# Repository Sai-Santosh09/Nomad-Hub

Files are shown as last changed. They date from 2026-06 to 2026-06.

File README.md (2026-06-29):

# NomadHub

NomadHub is a compact travel-inspired USB hub PCB designed in **KiCad**. It provides reliable USB connectivity through one USB Type-C upstream port, two USB Type-C downstream ports, and two USB Type-A downstream ports using the SL2.1S USB 2.0 Hub Controller.

## Features

- Compact travel-friendly PCB
- USB Type-C upstream port
- 2 × USB Type-C downstream ports
- 2 × USB Type-A downstream ports
- SL2.1S USB 2.0 Hub Controller
- 2-layer PCB design
- USB 2.0 compliant routing
- Gerber files included

## Images




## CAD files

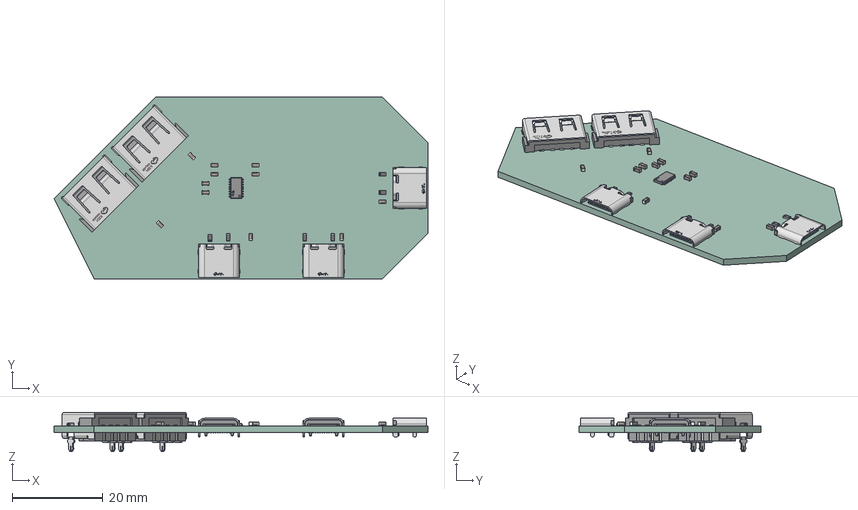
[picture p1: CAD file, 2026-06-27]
.step
82.3 x 40.0 x 8.60 mm
C_0603_1608Metric x 11
R_0603_1608Metric x 6
USB-C-SMD_TYPE-C-6PIN-2MD-073 x 3
SSOP-16_L4.6-W2.6-P0.53-LS4.0-BL
USB-A-TH_10.0QHHTZB6.3 x 2
USB Hub_PCB

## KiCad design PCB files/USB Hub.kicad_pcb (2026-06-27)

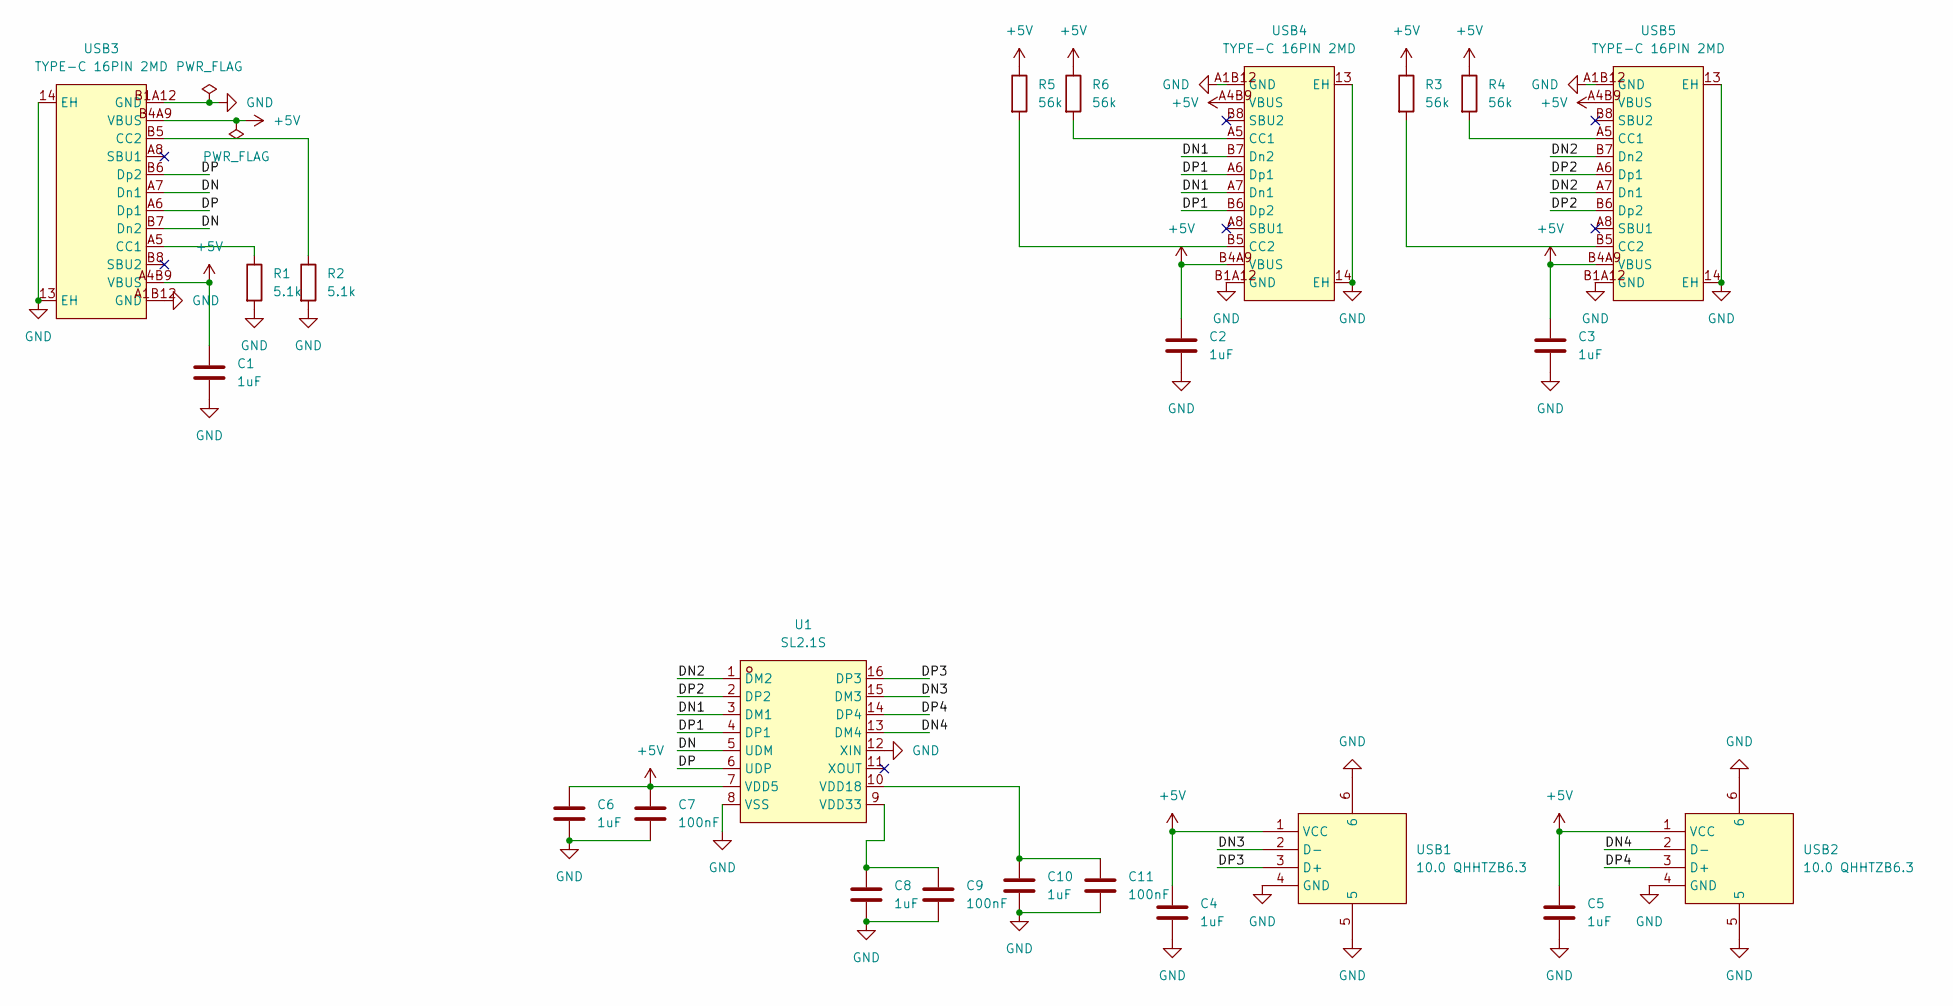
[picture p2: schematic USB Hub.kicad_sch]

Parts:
C1, C2, C3, C4, C5, C6, C8, C10: 1uF; C_0603_1608Metric
C7, C9, C11: 100nF; C_0603_1608Metric
R1, R2: 5.1k; R_0603_1608Metric
R3, R4, R5, R6: 56k; R_0603_1608Metric
U1: SL2.1S; SSOP-16_L4.6-W2.6-P0.53-LS4.0-BL; MPN SL2.1s; LCSC Part C2684433
USB1, USB2: 10.0 QHHTZB6.3; USB-A-TH_10.0QHHTZB6.3; MPN 10.0 QHHTZB6.3; LCSC Part C668591
USB3, USB4, USB5: TYPE-C 16PIN 2MD; USB-C-SMD_TYPE-C-16PIN-2MD-073; MPN TYPE-C 16PIN 2MD(073); LCSC Part C2765186

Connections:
+5V: C1.1, C2.1, C3.1, C4.1, C5.1, C6.1, C7.1, R3.1, R4.1, R5.1, R6.1, U1.7 (VDD5), USB1.1 (VCC), USB2.1 (VCC), USB3.A4B9 (VBUS), USB3.B4A9 (VBUS), USB4.A4B9 (VBUS), USB4.B4A9 (VBUS), USB5.A4B9 (VBUS), USB5.B4A9 (VBUS)
/DN: U1.5 (UDM), USB3.A7 (Dn1), USB3.B7 (Dn2)
/DN1: U1.3 (DM1), USB4.A7 (Dn1), USB4.B7 (Dn2)
/DN2: U1.1 (DM2), USB5.A7 (Dn1), USB5.B7 (Dn2)
/DN3: U1.15 (DM3), USB1.2 (D-)
/DN4: U1.13 (DM4), USB2.2 (D-)
/DP: U1.6 (UDP), USB3.A6 (Dp1), USB3.B6 (Dp2)
/DP1: U1.4 (DP1), USB4.A6 (Dp1), USB4.B6 (Dp2)
/DP2: U1.2 (DP2), USB5.A6 (Dp1), USB5.B6 (Dp2)
/DP3: U1.16 (DP3), USB1.3 (D+)
/DP4: U1.14 (DP4), USB2.3 (D+)
GND: C1.2, C2.2, C3.2, C4.2, C5.2, C6.2, C7.2, C8.2, C9.2, C10.2, C11.2, R1.2, R2.2, U1.8 (VSS), U1.12 (XIN), USB1.4 (GND), USB1.5, USB1.6, USB2.4 (GND), USB2.5, USB2.6, USB3.13 (EH), USB3.14 (EH), USB3.A1B12 (GND), USB3.B1A12 (GND), USB4.13 (EH), USB4.14 (EH), USB4.A1B12 (GND), USB4.B1A12 (GND), USB5.13 (EH), USB5.14 (EH), USB5.A1B12 (GND), USB5.B1A12 (GND)
unnamed: C10.1, C11.1, U1.10 (VDD18)
unnamed: C8.1, C9.1, U1.9 (VDD33)
unnamed: R1.1, USB3.A5 (CC1)
unnamed: R2.1, USB3.B5 (CC2)
unnamed: R6.2, USB4.A5 (CC1)
unnamed: R5.2, USB4.B5 (CC2)
unnamed: R4.2, USB5.A5 (CC1)
unnamed: R3.2, USB5.B5 (CC2)

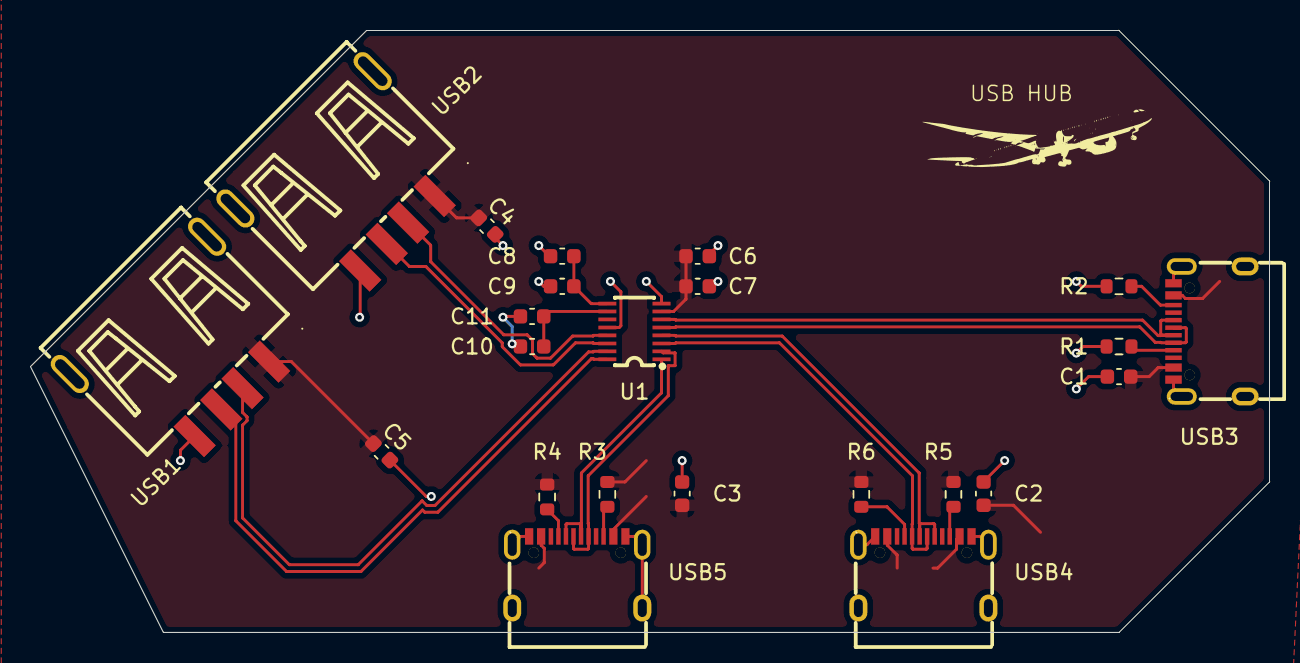
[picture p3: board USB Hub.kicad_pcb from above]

Board: 2 copper layers, 82.3 x 40.0 mm, 23 parts (0 on the bottom side), 20 nets.
